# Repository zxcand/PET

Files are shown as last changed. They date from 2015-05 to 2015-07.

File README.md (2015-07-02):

## What is iPET?
- a robot pet which can follow us around
- a robot pet we can control it remotely
- a robot pet showing us what it sees

## Video
http://youtu.be/Oe8pGG040HU

## Work
#### Hardware:
- raspberry pi model B+ (with pi camera)
- two motors and two wheels
- 3D models designed by ourselves (see:  )

#### Software architecture:
#####Algorithm
1. detect faces in current frame, and choose the biggest one to track
2. in following frames
   1. track the face
   2. see if we lose track of the face, yes -> goto step 1
   3. move the face to the center of the frame

#####Implementation
we have several classes: PET, camera, controller, tracker, face detector

######PET
```
while True:
  get frame <== from camera
  track certain area <== by tracker
  try to move the area to the center of the frame <== use controller
```
######camera
> interface of piCam

######controller
> 
interface of motors  
provide 5 functions: **rotateLeft**, **rotateRight**, **goForward**, **goBackward**, **stay**

######tracker
```
if we lose track of face:
  detect face <== by face detector
  mark the face as "tracking area"

use camshift to track "tracking area"
```
######face detector
```
detect faces
return area of the biggest one
```

## Authors and Contributors
* [Fan Wang] (https://github.com/zxcand)  
* [Chih-Yang Chen] (https://github.com/Jayis)  
* Keng-Ming Lee  
**instructor** : Wei-Chao Chen

## Reference
1. *Rainer Lienhart and Jochen Maydt. An Extended Set of Haar-like Features for Rapid Object Detection. IEEE ICIP 2002, Vol. 1, pp. 900-903, Sep. 2002*
[[Implemented by OpenCV]] (http://docs.opencv.org/modules/objdetect/doc/cascade_classification.html?highlight=cascadeclassifier)
2. *Bradski, G.R. “Computer Vision Face Tracking for Use in a Perceptual User Interface”, Intel, 1998*
[[Implemented by OpenCV]] (http://docs.opencv.org/modules/video/doc/motion_analysis_and_object_tracking.html)

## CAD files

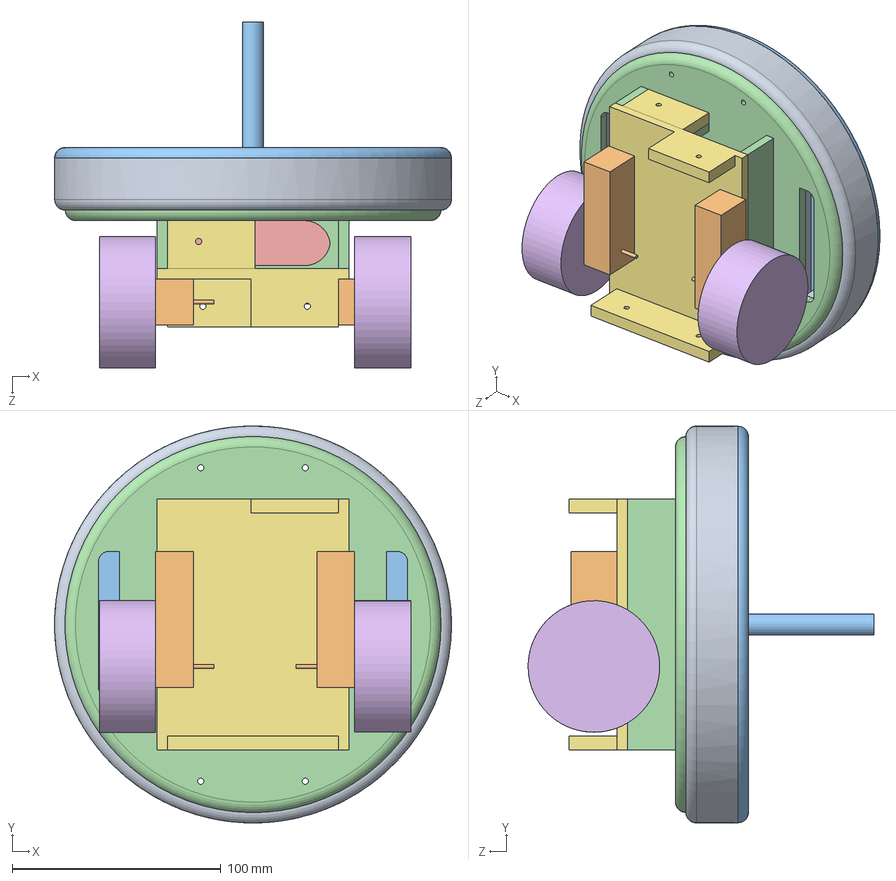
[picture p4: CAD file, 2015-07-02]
models/v5/組合件1.SLDASM
190.0 x 190.0 x 165.5 mm
main_structure
Motor x 2
Top_cover
base
powerbank
wheel x 2
base_COVER

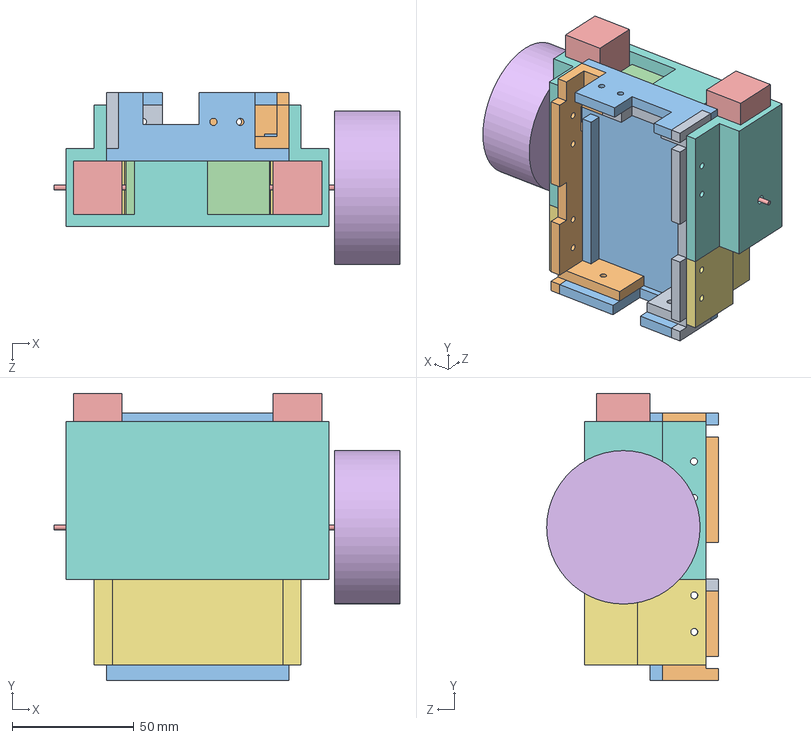
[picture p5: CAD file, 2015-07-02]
models/v5/組合件3.SLDASM
142.1 x 118.0 x 70.5 mm
Wall2
Wall
base_COVER
asus_powerbank
Motor x 2
wheel
powerbank._keeper_1SLDPRT
powerbank._keeper_2SLDPRT

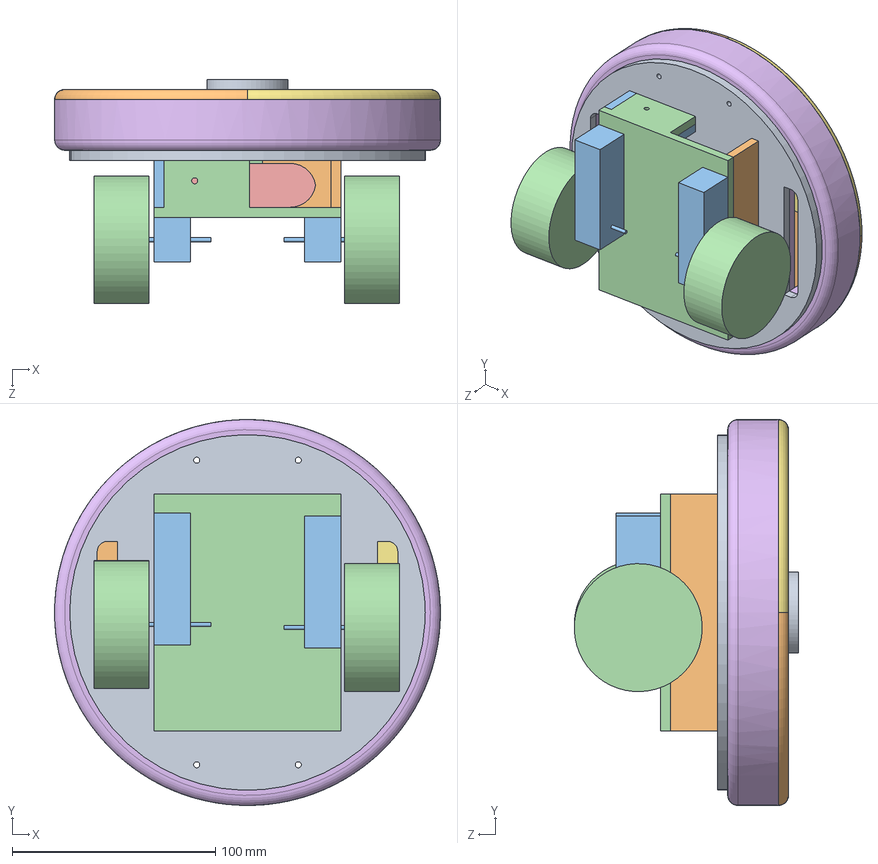
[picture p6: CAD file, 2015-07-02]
models/v5/組合件2.SLDASM
190.0 x 190.0 x 110.5 mm
base_laser
Wall
Wall2
base_COVER
powerbank
main_structure
Top_cover_2 x 2
base_COVER_top
base_COVER_bot
Top_cover x 2
Motor x 2
wheel x 2

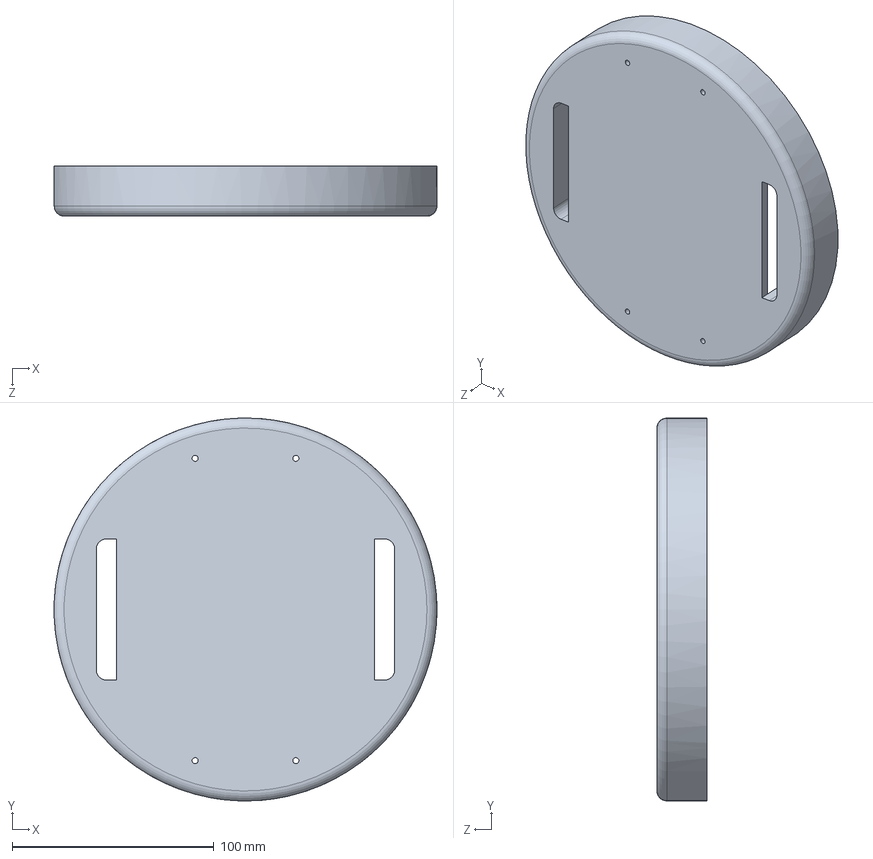
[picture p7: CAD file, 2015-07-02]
models/v5/main_structure.SLDPRT
190.0 x 190.0 x 25.0 mm

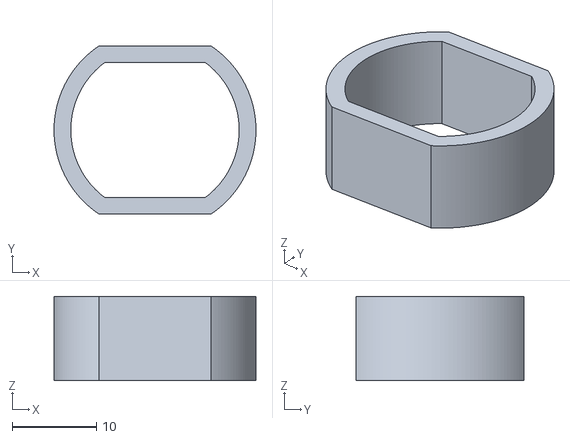
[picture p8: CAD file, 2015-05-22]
models/arduino/motor_holder2.stl
24.0 x 20.0 x 10.0

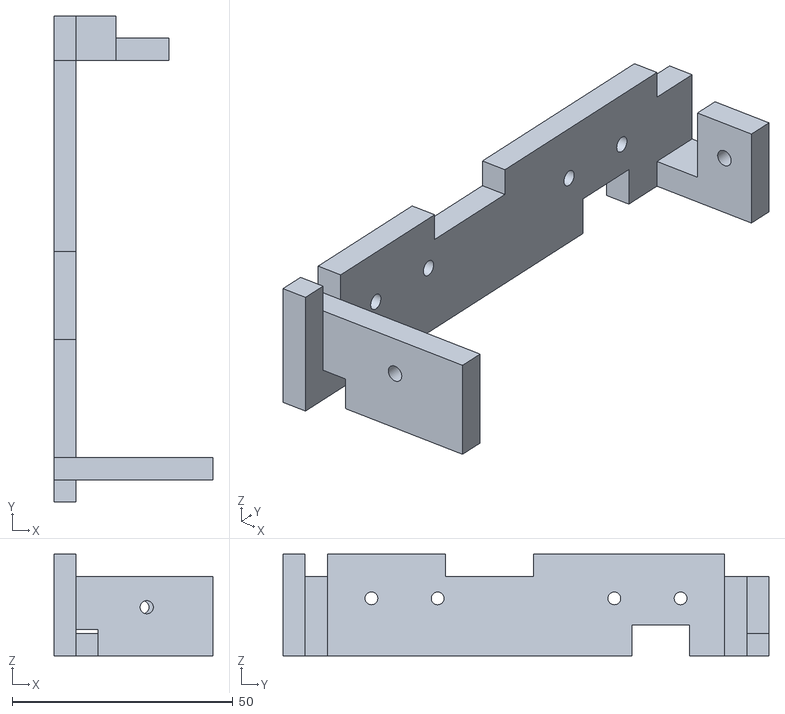
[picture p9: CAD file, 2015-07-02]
models/final/wall.STL
36.0 x 110.0 x 23.0

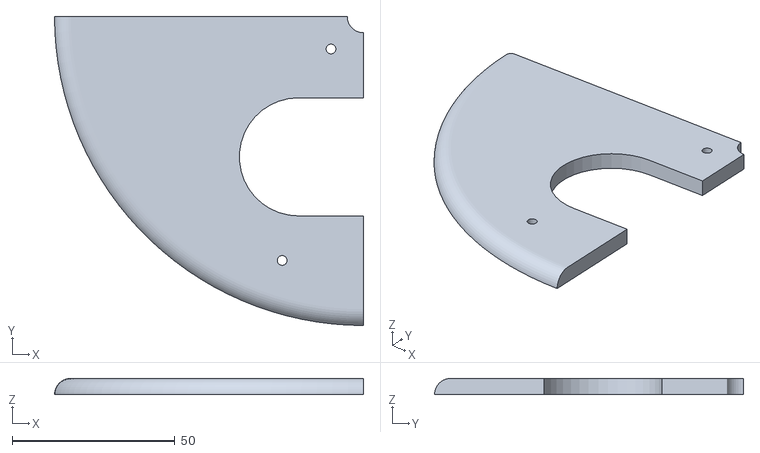
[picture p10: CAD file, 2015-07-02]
models/v5/Top_cover_2pics.STL
95.0 x 95.0 x 5.00

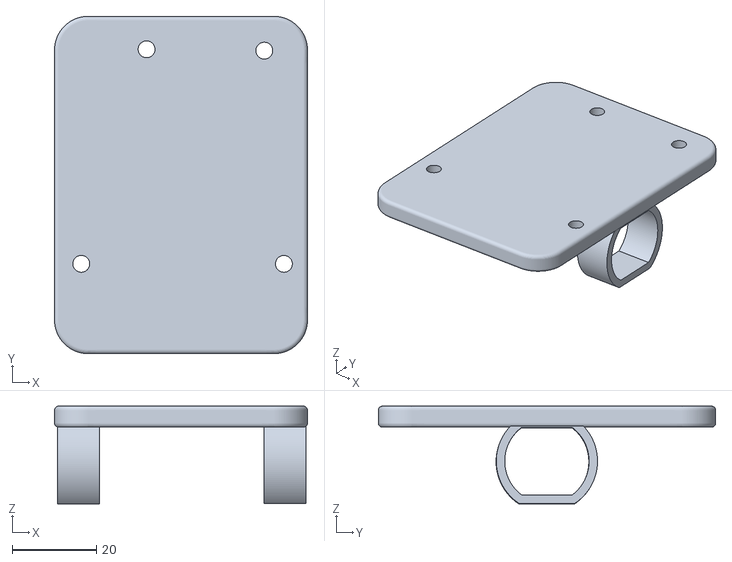
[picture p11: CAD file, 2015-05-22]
models/arduino/mybase.stl
60.0 x 80.0 x 23.2

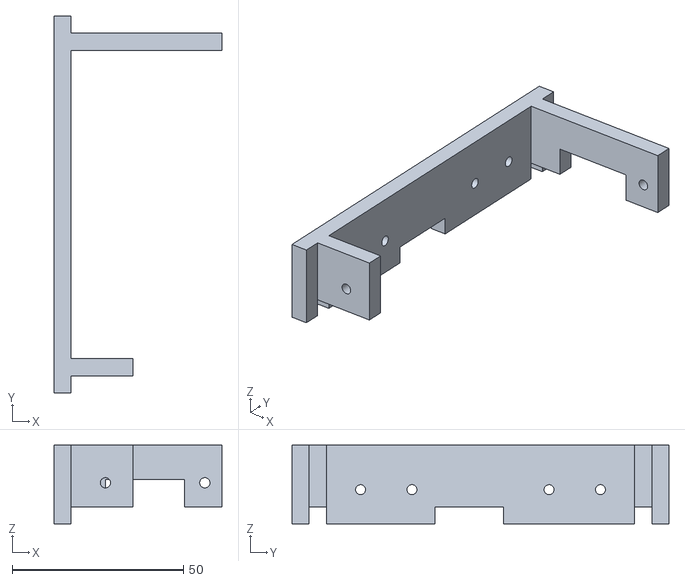
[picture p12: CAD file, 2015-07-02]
models/final/wall2.STL
49.0 x 110.0 x 23.0

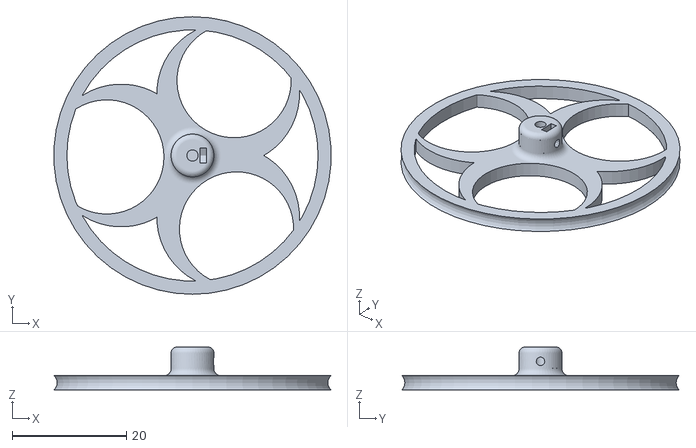
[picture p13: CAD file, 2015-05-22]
models/arduino/wheel.stl
48.5 x 48.6 x 7.50

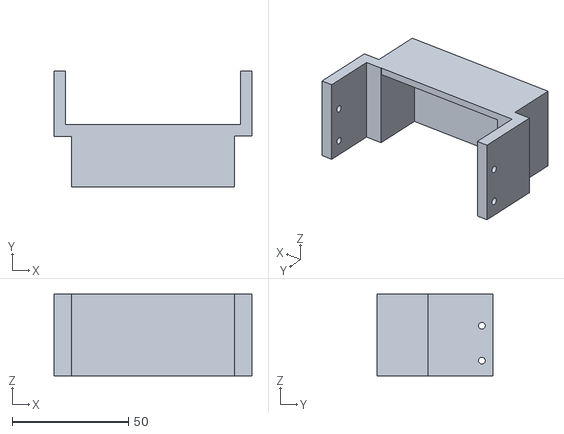
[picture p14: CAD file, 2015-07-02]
models/final/power_keeper.STL
85.0 x 50.0 x 35.0

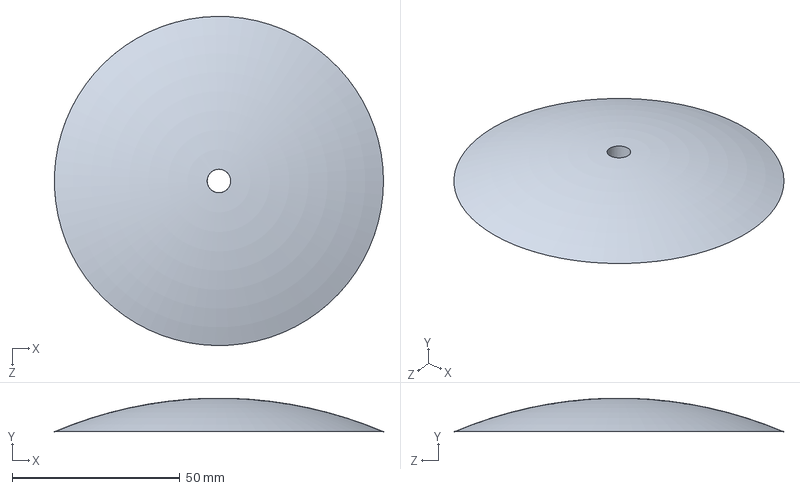
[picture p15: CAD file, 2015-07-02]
models/v5/top_bearing.SLDPRT
97.9 x 9.95 x 98.0 mm

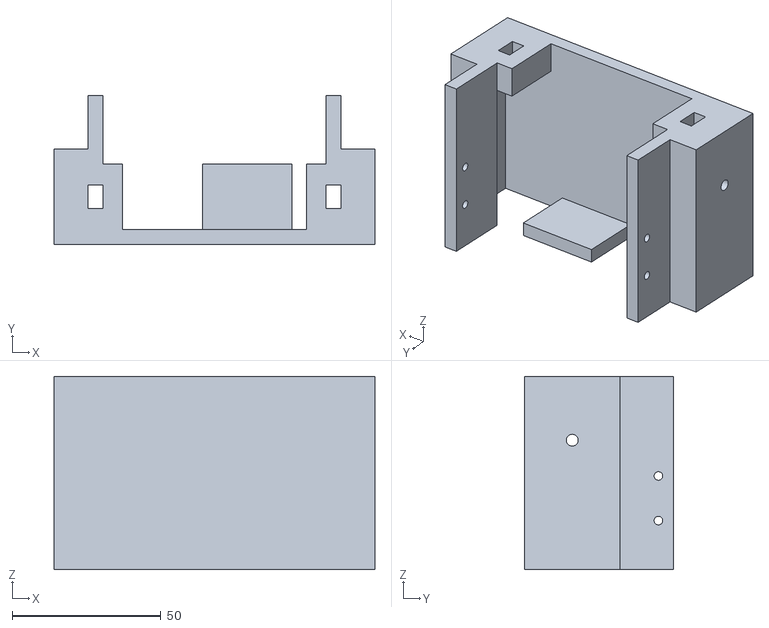
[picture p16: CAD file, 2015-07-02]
models/final/power_keeper2.STL
108.0 x 50.0 x 65.0

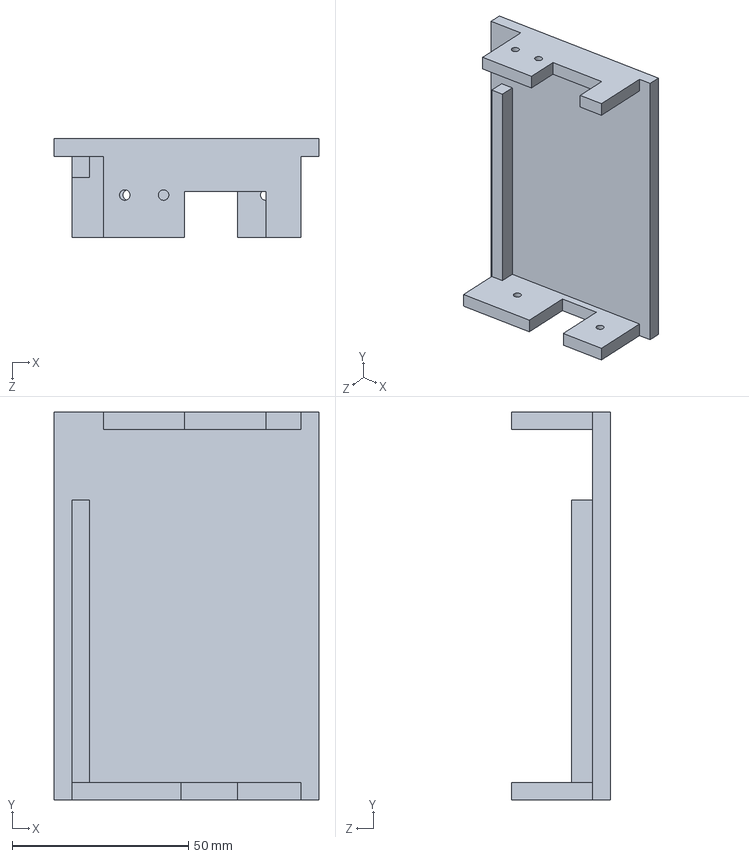
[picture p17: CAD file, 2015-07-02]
models/v5/base_COVER.SLDPRT
75.0 x 110.0 x 28.0 mm

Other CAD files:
models/v5/powerbank._keeper_2SLDPRT.SLDPRT
models/v5/powerbank.SLDPRT
models/v5/Wall1.SLDPRT
models/v5/Top_cover.SLDPRT
models/v1/Wheel.SLDPRT
models/v1/base.SLDPRT
models/v1/out_sphere.SLDPRT
models/v1/spring.SLDPRT
models/v1/top_base.SLDPRT
models/v1/top_bear.SLDPRT
models/v2/Ball_Surface.SLDPRT
models/v2/Motor.SLDPRT
models/v2/Top_cover.SLDPRT
models/v2/Top_cover.STL
models/v2/Top_cover_2.SLDPRT
models/v2/Top_cover_2_2pics.STL
models/v2/Wall.SLDPRT
models/v2/Wall.STL
models/v2/Wall2.SLDPRT
models/v2/base.SLDPRT
models/v2/base_COVER.SLDPRT
models/v2/base_COVER_bot.SLDPRT
models/v2/base_COVER_top.SLDPRT
models/v2/base_laser.DWG
models/v2/base_laser.SLDPRT
models/v2/main_structure.STL
models/v2/powerbank.SLDPRT
models/v2/wheel.SLDPRT
models/v2/組合件2.SLDASM
models/v3/Ball_Surface.SLDPRT
models/v3/Motor.SLDPRT
models/v3/Top_cover.SLDPRT
models/v3/Top_cover.STL
models/v3/Top_cover_2.SLDPRT
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

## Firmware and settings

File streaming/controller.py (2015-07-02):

import curses
import threading
import RPi.GPIO as GPIO
from numpy import interp

PWM_FREQ = 50 #100
PWM_dt = 1000 / PWM_FREQ
DUTY_MAX_dt = 2.0
DUTY_MIN_dt = 0.5
DUTY_MAX = 100 * DUTY_MAX_dt / PWM_dt
DUTY_MIN = 100 * DUTY_MIN_dt / PWM_dt
ANGLE_MAX = 180
ANGLE_MIN = 0

LED_PIN    = 26 #p
SERVO_PIN  = 18 #p12 
MOTOR_PIN1 = 27 #p13  IN1 on L298
MOTOR_PIN2 = 22 #p15  IN2 on L298
MOTOR_PIN3 = 23 #p16  IN3 on L298
MOTOR_PIN4 = 24 #p18  IN4 on L298

MOTOR_STAY = 0
MOTOR_FORWARD = 1
MOTOR_BACKWARD = 2

DEG_TO_SEC = 1.0/90

class Controller:
	no_thread   = 0
	servo_angle = 90

	def __init__(self):
		GPIO.setmode(GPIO.BCM)
		GPIO.setup(LED_PIN, GPIO.OUT)
		GPIO.setup(SERVO_PIN, GPIO.OUT)
		
		GPIO.setup(MOTOR_PIN1, GPIO.OUT)
		GPIO.setup(MOTOR_PIN2, GPIO.OUT)
	
		GPIO.setup(MOTOR_PIN3, GPIO.OUT)
		GPIO.setup(MOTOR_PIN4, GPIO.OUT)
		
		self.servo_pwm = GPIO.PWM(SERVO_PIN, PWM_FREQ) 
		self.servo_pwm.start((DUTY_MAX + DUTY_MIN)/2) #init duty cycle
		self.goStay() 
	def __del__(self):
		self.servo_pwm.stop()	
		GPIO.cleanup()

	def setLed(self, turnOn):
		if turnOn:
			GPIO.setup(LED_PIN, GPIO.HIGH)
		else:
			GPIO.setup(LED_PIN, GPIO.LOW)

	def setServo(self):
		print self.servo_angle
		duty = interp(self.servo_angle,[ANGLE_MIN,ANGLE_MAX],[DUTY_MIN,DUTY_MAX])
		self.servo_pwm.ChangeDutyCycle(duty)

	def lookUpper(self,angle):
		self.servo_angle = min(ANGLE_MAX, self.servo_angle + angle)
		self.setServo()

	def lookLower(self,angle):
		self.servo_angle = max(ANGLE_MIN, self.servo_angle - angle)
		self.setServo()

	def setMotors(self, motion1, motion2):
		if motion1 == MOTOR_STAY:
			GPIO.output(MOTOR_PIN1, GPIO.LOW)
			GPIO.output(MOTOR_PIN2, GPIO.LOW)
		elif motion1 == MOTOR_FORWARD:
			GPIO.output(MOTOR_PIN1, GPIO.HIGH)
			GPIO.output(MOTOR_PIN2, GPIO.LOW)
		else:
			GPIO.output(MOTOR_PIN1, GPIO.LOW)
			GPIO.output(MOTOR_PIN2, GPIO.HIGH)

		if motion2 == MOTOR_STAY:
			GPIO.output(MOTOR_PIN3, GPIO.LOW)
			GPIO.output(MOTOR_PIN4, GPIO.LOW)
		elif motion2 == MOTOR_FORWARD:
			GPIO.output(MOTOR_PIN3, GPIO.HIGH)
			GPIO.output(MOTOR_PIN4, GPIO.LOW)
		else:
			GPIO.output(MOTOR_PIN3, GPIO.LOW)
			GPIO.output(MOTOR_PIN4, GPIO.HIGH)

	def goStayLater(self):
		self.no_thread  = self.no_thread - 1
		if self.no_thread == 0:
			self.goStay()

	def goStay(self):
		self.setMotors( MOTOR_STAY, MOTOR_STAY)

	def goForward(self):
		self.setMotors( MOTOR_FORWARD, MOTOR_FORWARD)

	def goBackward(self):	
		self.setMotors( MOTOR_BACKWARD, MOTOR_BACKWARD)
	
	def goLeft(self):
		self.setMotors( MOTOR_BACKWARD, MOTOR_FORWARD)

	def goRight(self):
		self.setMotors( MOTOR_FORWARD, MOTOR_BACKWARD)

	
	def goForwardLength(self, degree):
		self.setMotors( MOTOR_FORWARD, MOTOR_FORWARD)
		self.no_thread = self.no_thread + 1
		t = threading.Timer( degree*DEG_TO_SEC, self.goStayLater)
		t.start() 

	def goBackLength(self,degree):	
		self.setMotors( MOTOR_BACKWARD, MOTOR_BACKWARD)
		self.no_thread = self.no_thread + 1
		t = threading.Timer( degree*DEG_TO_SEC, self.goStayLater)
		t.start() 

	def goLeftDegree(self,degree):
		self.setMotors( MOTOR_BACKWARD, MOTOR_FORWARD)
		self.no_thread = self.no_thread + 1
		t = threading.Timer(degree*DEG_TO_SEC, self.goStayLater)
		t.start() 

	def goRightDegree(self,degree):
		self.setMotors( MOTOR_FORWARD, MOTOR_BACKWARD)
		self.no_thread = self.no_thread + 1
		t = threading.Timer(degree*DEG_TO_SEC, self.goStayLater)
		t.start() 

if __name__=="__main__":
	con = Controller()

	screen = curses.initscr()
	curses.cbreak()
	curses.noecho()
	screen.keypad(True)
	
	try:
		while True:
			key = screen.getch()
			if key == ord('q'):
				screen.addstr(0, 0, 'quit ')
				break
			elif key == ord('z'):
				con.lookUpper(10)
				screen.addstr(0, 0, 'upper')
			elif key == ord('x'):
				con.lookLower(10)
				screen.addstr(0, 0, 'lower')
			
			elif key == ord('w'):
				screen.addstr(0, 0, 'on ')
				con.setLed(True)
			
			elif key == ord('e'):
				screen.addstr(0, 0, 'off ')
				con.setLed(False)
			
			elif key == ord('s'):
				screen.addstr(0, 0, 'stay ')
				con.goStay()
			elif key == curses.KEY_UP: #Up arrow
				screen.addstr(0, 0, 'up   ')
				con.goForward()
			elif key == curses.KEY_DOWN: #Down arrow
				screen.addstr(0, 0, 'down ')
				con.goBackward()
			elif key == curses.KEY_LEFT: #Left arrow
				screen.addstr(0, 0, 'left ')
				con.goLeft()
			elif key == curses.KEY_RIGHT: #Right arrow
				screen.addstr(0, 0, 'right')
				con.goRight()			
			else:
				screen.addstr(0, 0, 'err  ')

	finally:
		curses.nocbreak(); screen.keypad(0); curses.echo()
		curses.endwin()
		GPIO.cleanup()

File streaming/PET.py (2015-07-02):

import time
import cv2
import numpy as np

from controller import Controller
from camera import Camera
import tracker2 as tracker
from streamer import LocalStreamer

def calc_area((x0, y0, w, h)):
    return w*h
def get_center_x((x0, y0, w, h)):
    return x0+w/2
def get_center_y((x0, y0, w, h)):
    return y0+h/2

class PET():
    def __init__(self):
        #self.piStreamer = LocalStreamer()
        self.cam = Camera()
        self.controller = Controller()
        self.start_tracking = False
        self.track_window = (0,0,0,0)

        self.y_tolerance = 0.1
        self.default_ypos_percent = 0.4
        self.win_size_y = 240
        self.win_center_y = self.win_size_y * self.default_ypos_percent

        self.x_tolerance = 0.25
        self.default_xpos_percent = 0.5
        self.win_size_x = 320
        self.win_center_x = self.win_size_x * self.default_xpos_percent

        self.face_area = 10000 # 1600 == 1 m, 4000 == .3 m,
        self.dis_tolerance_closer = 2000
        self.dis_tolerance_farther = 1700

        self.DegPerPix = 0.2 # 0.2 at distance == 2 m
        self.dtPerDeg = 1.0/90
        self.step = 0.05

    def run(self):

        tr = tracker.tracker()
        t = time.time()
        while True:

            self.frame = self.cam.getMat()
            #self.frame = self.piStreamer.getFrame()

            tr_win = tr.track(self.frame)

            #print tr_win
            if calc_area(tr_win) > 0:
                self.start_tracking = True
                self.controller.setLed(True)
            else:
                self.start_tracking = False
                self.controller.setLed(False)
                self.controller.goStay()

            if self.start_tracking:
                #time.sleep(1.0/60)
                now = time.time()
                print int(1/(now-t)),'fps'
                t = now
                #time.sleep(1.0/60)
                print calc_area(tr_win)
                #--- x
                cur_center_x = get_center_x(tr_win)
                deviation_x = cur_center_x - self.win_center_x
                if deviation_x > self.win_size_x * self.x_tolerance:
                    #self.controller.goRight( self.step * (deviation_x) * self.DegPerPix )
                    self.controller.goRight()
                    #self.stop_t = now + self.step * (deviation_x) * self.DegPerPix * self.dtPerDeg
                    print "move right!!",self.step * (-deviation_x) * self.DegPerPix
                elif deviation_x < - self.win_size_x * self.x_tolerance:
                    print "move left!!",self.step * (deviation_x) * self.DegPerPix
                    #self.controller.goLeft( self.step * (-deviation_x) * self.DegPerPix )
                    self.controller.goLeft()
                    #self.stop_t = now + self.step * (-deviation_x) * self.DegPerPix * self.dtPerDeg
                else:
                    self.controller.goStay()
                    #print "stay in horizontal!!"
                #--- then distance
                #--- if all function work well
                #--- we should calc "distance = area / cos(theta)"
                    if calc_area(tr_win) - self.dis_tolerance_closer > self.face_area:
                        print "back off!!"
                        self.controller.goBackward()
                        self.stop_t = now #+ self.step * (deviation_x) * self.DegPerPix * self.dtPerDeg
                    elif calc_area(tr_win) + self.dis_tolerance_farther < self.face_area:
                        print "come forward!!"
                        self.controller.goForward()
                        self.stop_t = now #+ self.step * (deviation_x) * self.DegPerPix * self.dtPerDeg
                    else:
                        print "stay in distance!!"
                        self.stop_t = now
                        self.controller.goStay()
#'''

                #if self.stop_t <= now:
                if False:
                    self.controller.goStay()
#'''
                #print time.time() - now, "judging time"
                #--- y
                cur_center_y = get_center_y(tr_win)
                deviation_y = cur_center_y - self.win_center_y
                if deviation_y > self.win_size_y * self.y_tolerance:
                    print "move up your head!!"
                    # lower the cam
                    #self.controller.lookLower( self.step * (deviation_y) * self.DegPerPix )
                elif deviation_y < - self.win_size_y * self.y_tolerance:
                    print "lower your head!!"
                    #self.controller.lookUpper( self.step * (-deviation_y) * self.DegPerPix )
                    # raise the cam
                else:
                    print "stay in vertical!!"
                    # stay
#'''
'''            
            ch = 0xFF & cv2.waitKey(5)
            if ch == 27:
                break
            elif ch == ord("s"):
                self.face_area = calc_area(tr_win)
                self.start_tracking = True
#'''
#        cv2.destroyAllWindows()

if __name__ == '__main__':    
    PET().run()
        

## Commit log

2015-05-22 add models
    [motor_holder2.stl, mybase.stl, wheel.stl]
2015-06-02 add new models (diameter = 18cm)
    [Top_cover.STL, main_structure.STL]
2015-06-08 add threading, and fix bugs in streamer class
    [streamer.py]
2015-06-08 lock for streaming thread
2015-06-10 fix bug in finding face
    [camshift_tes2.py, tracker2.py]
2015-06-18 re-find-face
    if face too small or to big
    [camshift_tes2.py, tracker2.py]
2015-06-19 add pi motor controller and local testing program
2015-06-24 add servo in controller
2015-06-27 camera.py using pi cam added
2015-06-27 add camera in PET.py
2015-06-27 fix cascade path issue(using abs. path)
    [PET.py, camera.py, faceDetector.py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]
2015-06-28 modified by Fan and Harry on RPi
2015-06-29 fixed degree issue in controller test case
    [controller.py]
2015-07-02 update final model
    [base.STL, power_keeper.STL, power_keeper2.STL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]
